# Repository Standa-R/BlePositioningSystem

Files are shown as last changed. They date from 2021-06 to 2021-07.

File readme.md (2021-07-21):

# BLE positioning system

The project includes a short description of source code for Anchors and Tags. PCB design files are also included.

If the use of this source code for Anchors and Tags or PCB design leading to a scientific publication, please, cite our work:

```
@article{Polak_Sensors_2021,
     doi = {10.3390/s21134605},
     url = {https://doi.org/10.3390/s21134605},
     year = {2021},
     month = {July},
     publisher = {MDPI},
     volume = {21},
     number = {13},
     pages = {1--25},
     author = {Ladislav Polak and Stanislav Rozum and Martin Slanina and Tomas Bravenec and Tomas Fryza and Aggelos Pikrakis},
     title = {Received Signal Strength Fingerprinting-Based Indoor Location Estimation Employing Machine Learning},
     journal = {Sensors}
}
```

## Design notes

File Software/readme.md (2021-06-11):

# BleIPS

This folder contains simple application (hastily written) that logs and plots Anchor reports in real time. 

First it subscribes for anchor reports from Raspberry Pi B+ via UDP command. After that it receives anchor reports which are plotted and logged to *csv format.

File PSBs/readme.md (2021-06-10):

# PCB design

This folder contains Anchor's PCB source files from Autodesk Eagle. The mainBoard includes board-to-board connectors for extension boards. There are two extension boards, namely BLEModule and ZigBeeModule. Both are directly put into the schematic of mainBoard.

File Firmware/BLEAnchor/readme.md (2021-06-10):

# BLE anchor firmware

Here you can see the projects for Keil MDK-ARM uVision and STM32CubeMX. 

The MCU runs three cooperative tasks (nonos code):

- BleTask
- ZigBeeTask
- ServiceUartIFTask

## Ble task

Ble task controls four BL652 modules. It starts transmitting/receiving mode deepening on positioning mode (Remote and Self-positioning).

During remote positioning operation it awaits for reports send from BL652 module via uart. Because each advertisementshould be received by all modules we should get four uart messages, each with RSS reading per modules. Due to processing times these messages are not in sync. Therefore the Ble task implements queue. The key for items in queue is address or id of BLE device. On Ble uart report received, the queue is searched and the relevant RSS field in filled. In the device address in not found a new item is created. If all RSS fields are not filled in 4 milliseconds, the report is send regardless of missing readings as they are considered to be not received by the BL652.

## ZigBeeTask

Initializes the communication with ZigBee module ETRX357 and provides interface for control of Anchor.

## ServiceUartIFTask

This task is used as debug service, it saves the messages to buffer and than outputs to uart. It works similarly like prints to standard console output.

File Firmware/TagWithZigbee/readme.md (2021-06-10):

# BLE tag1 firmware (with Zigbee)

Here you can see the projects for Keil MDK-ARM uVision and STM32CubeMX. 

Tag1 uses evaluation board NUCLEO-F429ZI.

The MCU runs three cooperative tasks (nonos code):

- BleTask
- ZigBeeTask
- ServiceUartIFTask

## Ble task

Ble task controls a BL652 modules. It starts transmitting/receiving mode deepening on positioning mode (Remote and Self-positioning).

## ZigBeeTask

Initializes the communication with ZigBee module ETRX357 and provides interface for control of the Tag.

## ServiceUartIFTask

This task is used as debug service, it saves the messages to buffer and than outputs to uart. It works similarly like prints to standard console output.

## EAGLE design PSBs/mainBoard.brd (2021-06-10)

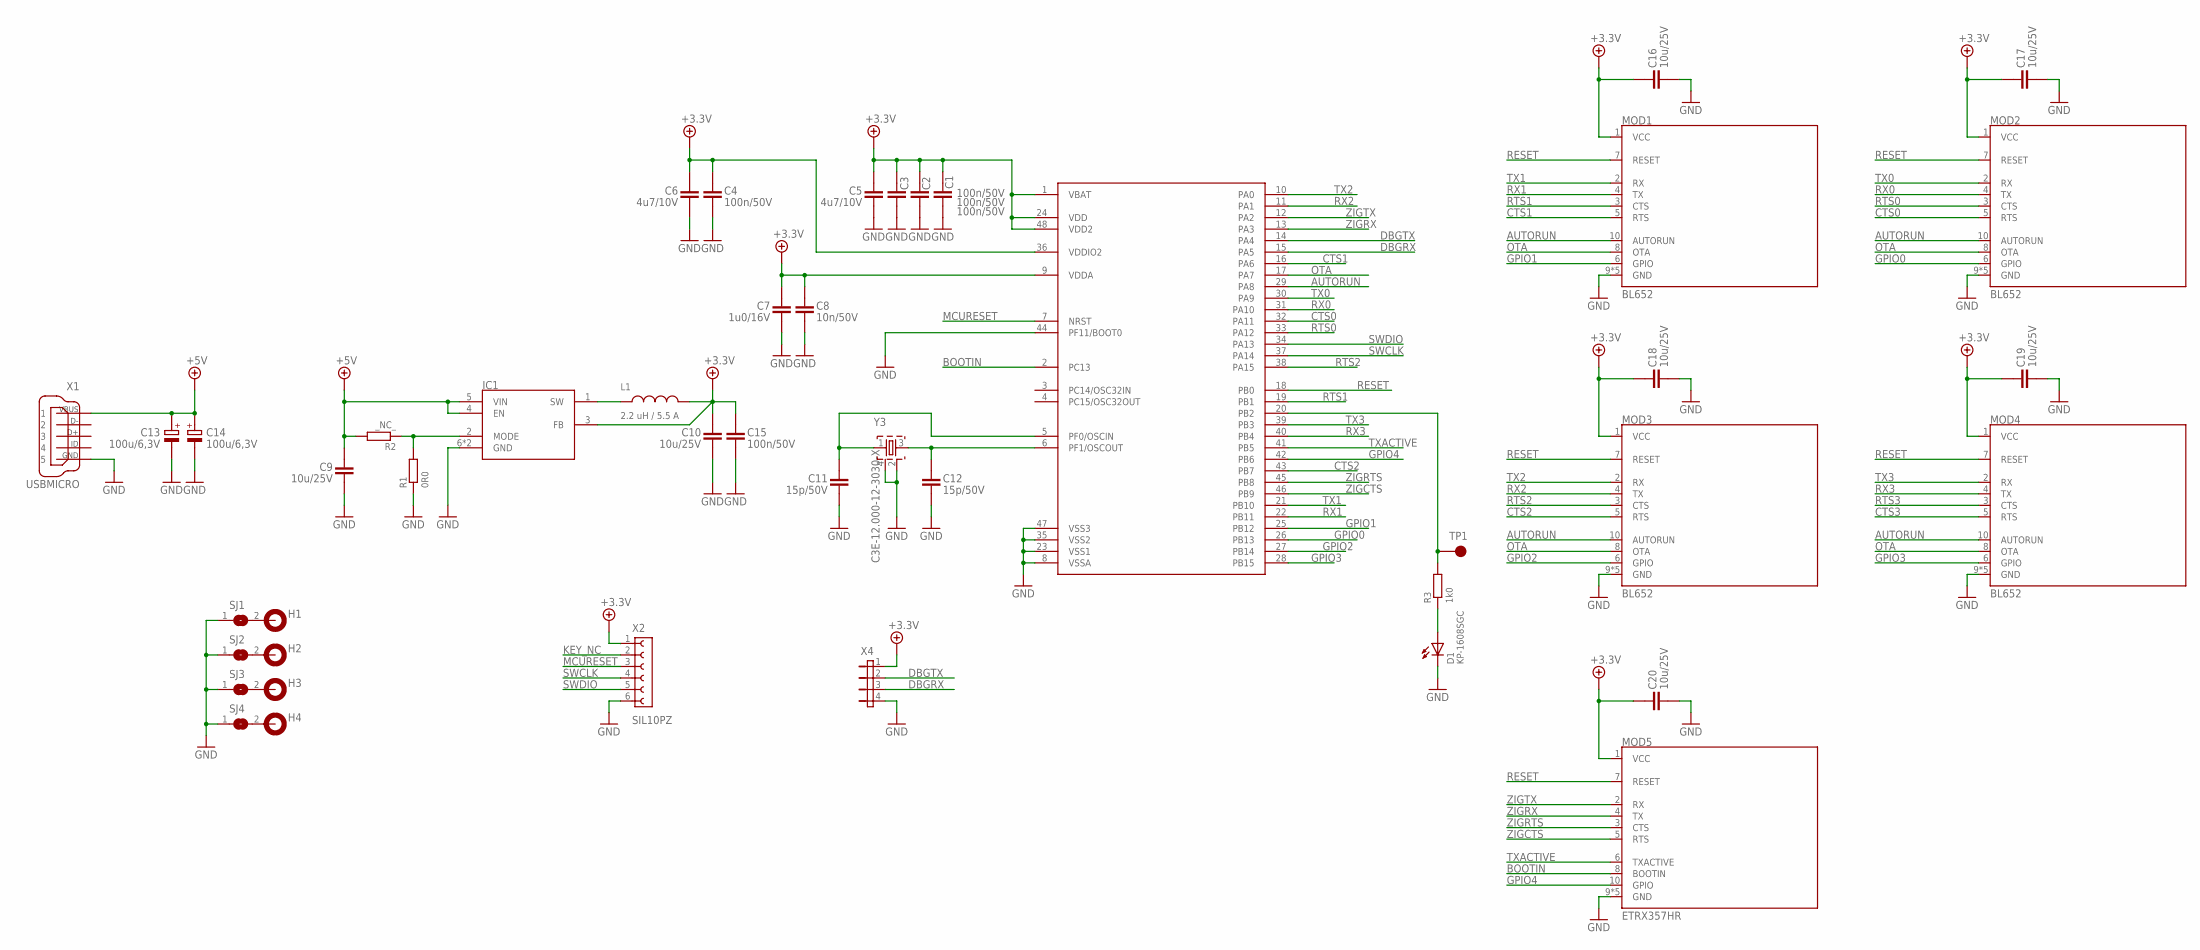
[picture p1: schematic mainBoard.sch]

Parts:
C1, C2, C3, C4, C15: 100N/50V,X7R,+/-10%_0603R; C0603R
C5, C6: 4U7/10V,X5R,+/-10%_0603R; C0603R
C7: 1U0/16V,X5R,+/-10%_0603R; C0603R
C8: 10N/50V,X7R,+/-10%_0603R; C0603R
C9, C10, C16, C17, C18, C19, C20: 10U/25V,X5R,+/-10%_0805R; C0805R
C11, C12: 15P/50V,COG/NPO,+/-5%_0603R; C0603R
C13, C14: 100U; CT6032
D1: KP-1608SGC; 0603
H1, H2, H3, H4: MOUNT-PAD-ROUND4.3; 4.3-PAD
IC0: STM32F091CCT; LQFP48
IC1: TPS62291
L1: 2U2_IHLP2020; 5.49X2X5.18MM
MOD1, MOD2, MOD3, MOD4: BLEMODULE; BLEMOD
MOD5: ZIGBEE; ZIGBEEMOD
R1: 0R0/0.1W,THICK_FILM,1%_0603R; R0603R
R2: _NC_/0.1W,THICK_FILM,1%_0603R; R0603R
R3: 1K0/0.1W,THICK_FILM,1%_0603R; R0603R
SJ1, SJ2, SJ3, SJ4: SJ_1-SMALL; SJ-SMALL
TP1: TEST-PAD_3.5X2-SMD; 3.5X2_SMD
X1: USBMICRO
X2: SOCKET_HADER-1X6; 1X06
X4: PIN_HEADER-1X4; 1X04
Y3: C3E-12.000-12-3030-X; 3.4X2.7X0.75

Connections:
+3.3V: C1.2, C2.2, C3.2, C4.2, C5.2, C6.2, C7.2, C8.2, C10.2, C15.2, C16.2, C17.2, C18.2, C19.2, C20.2, IC0.1 (VBAT), IC0.9 (VDDA), IC0.24 (VDD), IC0.36 (VDDIO2), IC0.48 (VDD2), IC1.3 (FB), L1.P$2 (2), MOD1.1 (VCC), MOD2.1 (VCC), MOD3.1 (VCC), MOD4.1 (VCC), MOD5.1 (VCC), X2.1, X4.1
+5V: C9.2, C13.+, C14.+, IC1.4 (EN), IC1.5 (VIN), R2.2, X1.1
AUTORUN: IC0.29 (PA8), MOD1.10 (AUTORUN), MOD2.10 (AUTORUN), MOD3.10 (AUTORUN), MOD4.10 (AUTORUN)
BOOTIN: IC0.2 (PC13), MOD5.8 (BOOTIN)
CTS0: IC0.32 (PA11), MOD2.5 (RTS)
CTS1: IC0.16 (PA6), MOD1.5 (RTS)
CTS2: IC0.43 (PB7), MOD3.5 (RTS)
CTS3: MOD4.5 (RTS)
DBGRX: IC0.15 (PA5), X4.3
DBGTX: IC0.14 (PA4), X4.2
GND: C1.1, C2.1, C3.1, C4.1, C5.1, C6.1, C7.1, C8.1, C9.1, C10.1, C11.1, C12.1, C13.-, C14.-, C15.1, C16.1, C17.1, C18.1, C19.1, C20.1, D1.2 (C), IC0.8 (VSSA), IC0.23 (VSS1), IC0.35 (VSS2), IC0.44 (PF11/BOOT0), IC0.47 (VSS3), IC1.6 (GND), IC1.EXP (GND), MOD1.9 (GND), MOD1.A1 (GND), MOD1.A2 (GND), MOD1.B1 (GND), MOD1.B2 (GND), MOD2.9 (GND), MOD2.A1 (GND), MOD2.A2 (GND), MOD2.B1 (GND), MOD2.B2 (GND), MOD3.9 (GND), MOD3.A1 (GND), MOD3.A2 (GND), MOD3.B1 (GND), MOD3.B2 (GND), MOD4.9 (GND), MOD4.A1 (GND), MOD4.A2 (GND), MOD4.B1 (GND), MOD4.B2 (GND), MOD5.9 (GND), MOD5.A1 (GND), MOD5.A2 (GND), MOD5.B1 (GND), MOD5.B2 (GND), R1.1, SJ1.1, SJ2.1, SJ3.1, SJ4.1, X1.5, X1.H1 (5), X1.H2 (5), X2.6, X4.4, Y3.2, Y3.4
GPIO0: IC0.26 (PB13), MOD2.6 (GPIO)
GPIO1: IC0.25 (PB12), MOD1.6 (GPIO)
GPIO2: IC0.27 (PB14), MOD3.6 (GPIO)
GPIO3: IC0.28 (PB15), MOD4.6 (GPIO)
GPIO4: IC0.42 (PB6), MOD5.10 (GPIO)
KEY_NC: X2.2
MCURESET: IC0.7 (NRST), X2.3
unnamed: IC1.1 (SW), L1.P$1 (1)
unnamed: D1.1 (A), R3.1
unnamed: IC0.20 (PB2), R3.2, TP1.TP
unnamed: IC1.2 (MODE), R1.2, R2.1
unnamed: H1.1, SJ1.2
unnamed: H2.1, SJ2.2
unnamed: H3.1, SJ3.2
unnamed: H4.1, SJ4.2
unnamed: C11.2, IC0.5 (PF0/OSCIN), Y3.1
unnamed: C12.2, IC0.6 (PF1/OSCOUT), Y3.3
OTA: IC0.17 (PA7), MOD1.8 (OTA), MOD2.8 (OTA), MOD3.8 (OTA), MOD4.8 (OTA)
RESET: IC0.18 (PB0), MOD1.7 (RESET), MOD2.7 (RESET), MOD3.7 (RESET), MOD4.7 (RESET), MOD5.7 (RESET)
RTS0: IC0.33 (PA12), MOD2.3 (CTS)
RTS1: IC0.19 (PB1), MOD1.3 (CTS)
RTS2: IC0.38 (PA15), MOD3.3 (CTS)
RTS3: MOD4.3 (CTS)
RX0: IC0.31 (PA10), MOD2.4 (TX)
RX1: IC0.22 (PB11), MOD1.4 (TX)
RX2: IC0.11 (PA1), MOD3.4 (TX)
RX3: IC0.40 (PB4), MOD4.4 (TX)
SWCLK: IC0.37 (PA14), X2.4
SWDIO: IC0.34 (PA13), X2.5
TX0: IC0.30 (PA9), MOD2.2 (RX)
TX1: IC0.21 (PB10), MOD1.2 (RX)
TX2: IC0.10 (PA0), MOD3.2 (RX)
TX3: IC0.39 (PB3), MOD4.2 (RX)
TXACTIVE: IC0.41 (PB5), MOD5.6 (TXACTIVE)
ZIGCTS: IC0.46 (PB9), MOD5.5 (RTS)
ZIGRTS: IC0.45 (PB8), MOD5.3 (CTS)
ZIGRX: IC0.13 (PA3), MOD5.4 (TX)
ZIGTX: IC0.12 (PA2), MOD5.2 (RX)

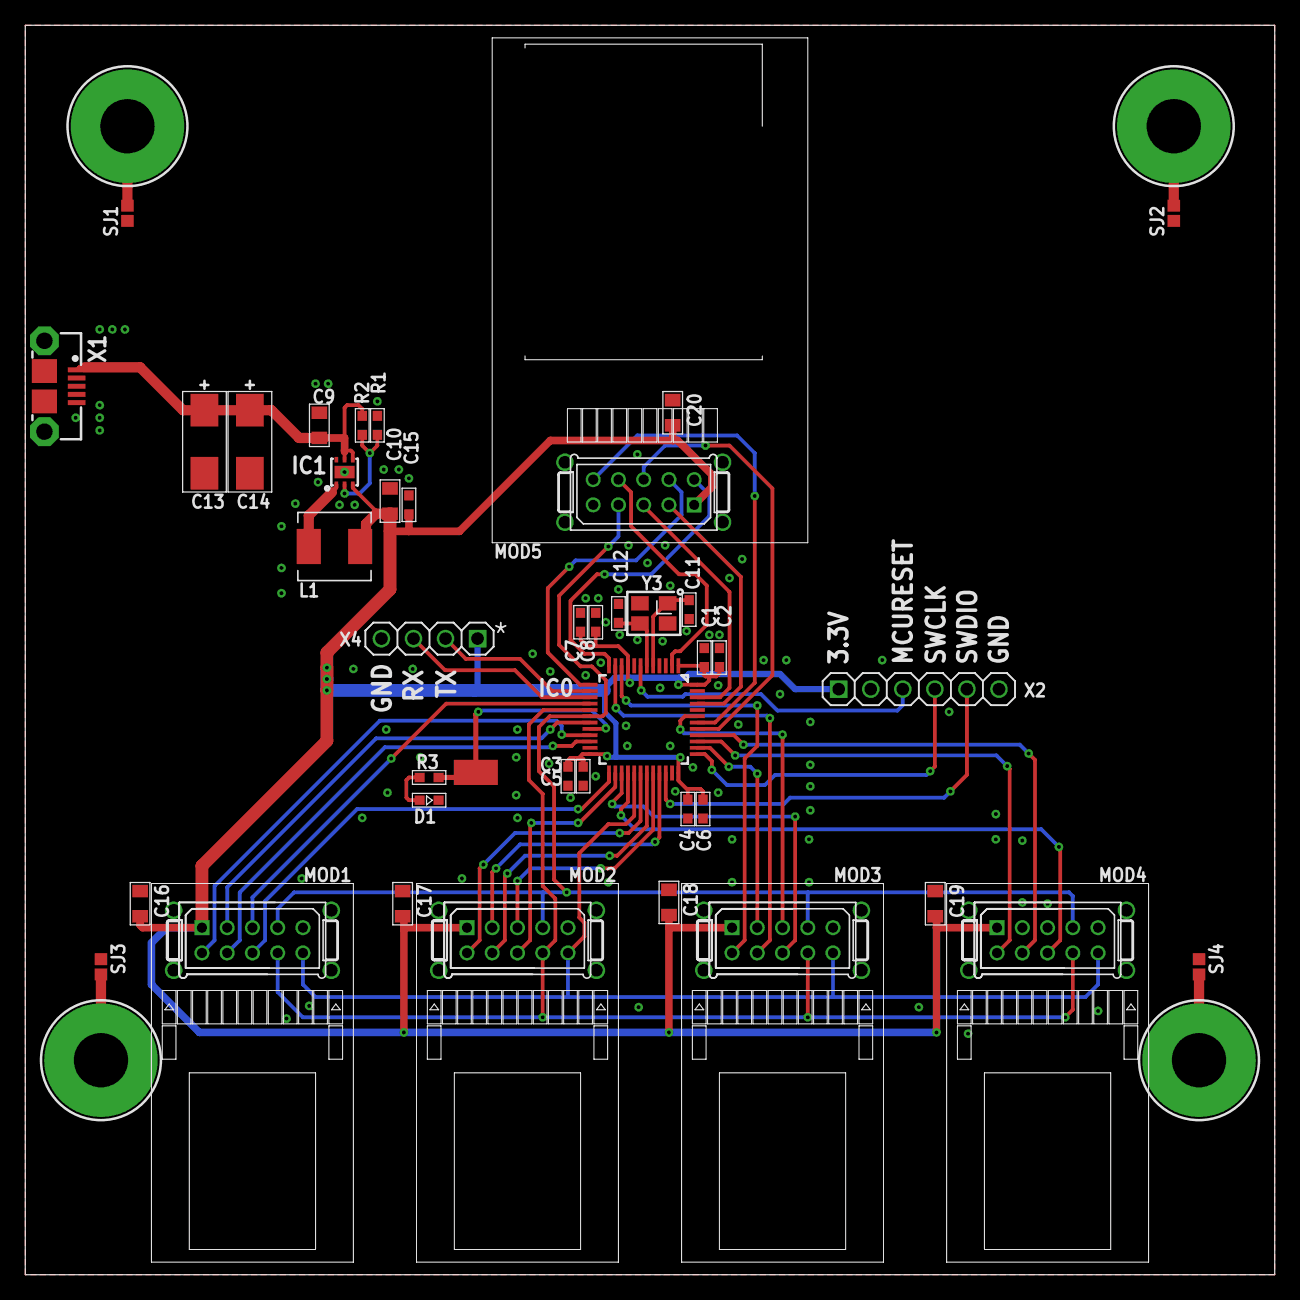
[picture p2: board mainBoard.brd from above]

Board: 4 copper layers, 99.0 x 99.0 mm, 45 parts (0 on the bottom side), 46 nets.

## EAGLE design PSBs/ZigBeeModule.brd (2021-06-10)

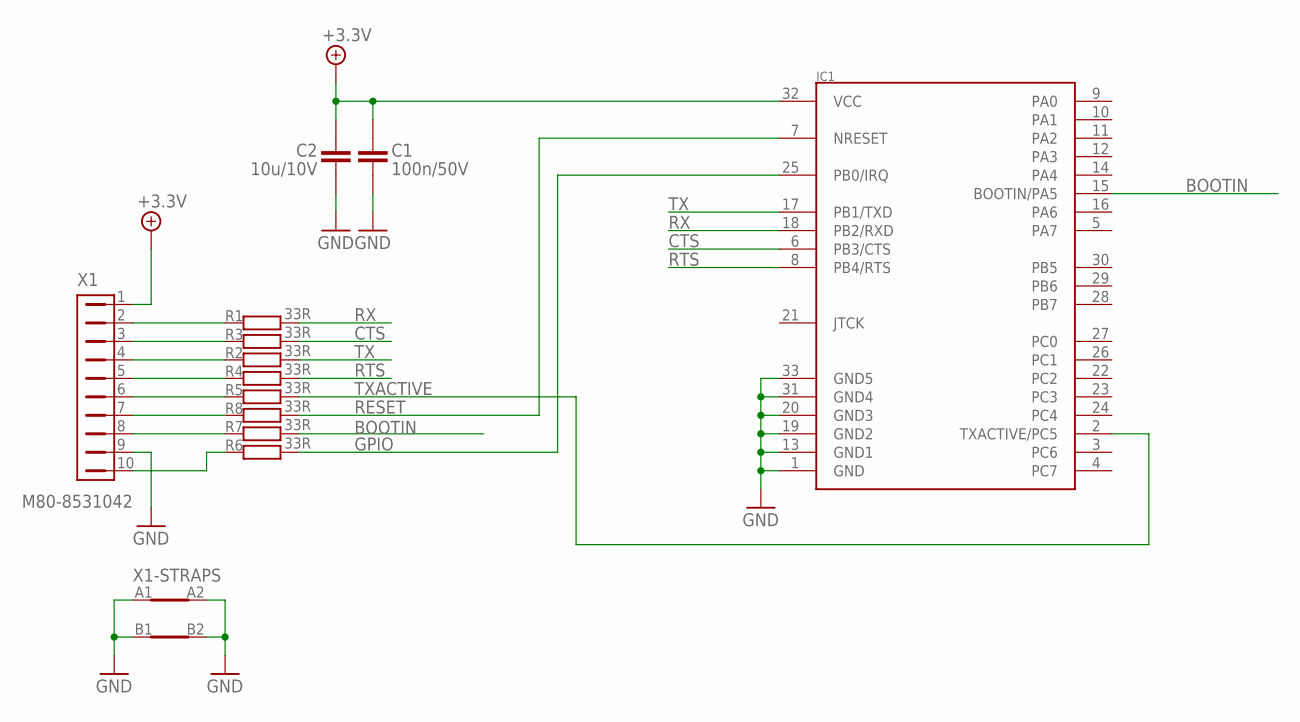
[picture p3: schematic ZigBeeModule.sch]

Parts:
C1: 100N/50V,X7R,+/-10%_0603R; C0603R
C2: 10U/10V,X5R,+/-20%_0603R; C0603R
IC1: ETRX357; ETRX3
R1, R2, R3, R4, R5, R6, R7, R8: 33R/0.1W,THICK_FILM,1%_0603R; R0603R
X1: M80-8531042; M80-85310-W_STRAPS

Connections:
+3.3V: C1.2, C2.2, IC1.32 (VCC), X1.1
BOOTIN: IC1.15 (BOOTIN/PA5), R7.2
CTS: IC1.6 (PB3/CTS), R3.2
GND: C1.1, C2.1, IC1.1 (GND), IC1.13 (GND1), IC1.19 (GND2), IC1.20 (GND3), IC1.31 (GND4), IC1.33 (GND5), X1.9, X1.A1, X1.A2, X1.B1, X1.B2
GPIO: IC1.25 (PB0/IRQ), R6.2
unnamed: R6.1, X1.10
unnamed: R1.1, X1.2
unnamed: R3.1, X1.3
unnamed: R2.1, X1.4
unnamed: R4.1, X1.5
unnamed: R5.1, X1.6
unnamed: R7.1, X1.8
unnamed: R8.1, X1.7
RESET: IC1.7 (NRESET), R8.2
RTS: IC1.8 (PB4/RTS), R4.2
RX: IC1.18 (PB2/RXD), R1.2
TX: IC1.17 (PB1/TXD), R2.2
TXACTIVE: IC1.2 (TXACTIVE/PC5), R5.2

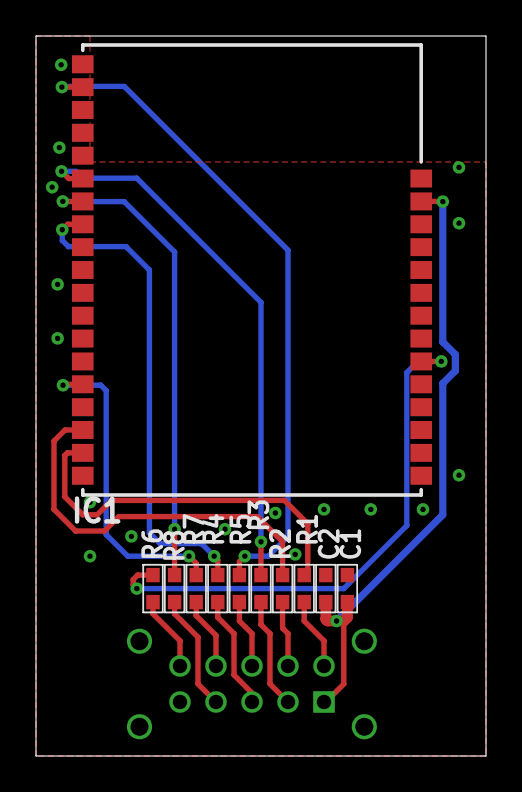
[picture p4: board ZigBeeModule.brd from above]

Board: 4 copper layers, 25.0 x 40.0 mm, 12 parts (1 on the bottom side), 18 nets.

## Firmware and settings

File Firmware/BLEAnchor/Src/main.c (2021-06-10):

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

/* Includes ------------------------------------------------------------------*/
#include "main.h"

/* USER CODE BEGIN Includes */
#include <stdbool.h>
#include <string.h>
#include "BLE.h"
#include "ZigBee.h"
#include "ServiceUartIF.h"

#pragma anon_unions
/* USER CODE END Includes */

RTC_HandleTypeDef hrtc;

UART_HandleTypeDef huart1;
UART_HandleTypeDef huart2;
UART_HandleTypeDef huart3;
UART_HandleTypeDef huart4;
UART_HandleTypeDef huart5;
UART_HandleTypeDef huart6;
DMA_HandleTypeDef hdma_usart1_rx;
DMA_HandleTypeDef hdma_usart1_tx;
DMA_HandleTypeDef hdma_usart2_rx;
DMA_HandleTypeDef hdma_usart2_tx;
DMA_HandleTypeDef hdma_usart3_rx;
DMA_HandleTypeDef hdma_usart3_tx;
DMA_HandleTypeDef hdma_usart4_rx;
DMA_HandleTypeDef hdma_usart4_tx;
DMA_HandleTypeDef hdma_usart5_rx;
DMA_HandleTypeDef hdma_usart5_tx;
DMA_HandleTypeDef hdma_usart6_rx;
DMA_HandleTypeDef hdma_usart6_tx;

void SystemClock_Config(void);
static void MX_GPIO_Init(void);
static void MX_DMA_Init(void);
static void MX_RTC_Init(void);
static void MX_USART1_UART_Init(void);
static void MX_USART2_UART_Init(void);
static void MX_USART3_UART_Init(void);
static void MX_USART4_UART_Init(void);
static void MX_USART5_UART_Init(void);
static void MX_USART6_UART_Init(void);
/* USER CODE BEGIN 0 */


//#define BUFFER_SIZE 256  /* must be power of two */
#define TX_BUFFER_SIZE 1024
//#define COMMAND_BUFFER_SIZE 128

void HAL_UART_ErrorCallback(UART_HandleTypeDef *huart)
{
    if(huart == &huart3)
    {
        if(huart->ErrorCode == HAL_UART_ERROR_FE)
        {
            __HAL_UART_CLEAR_FEFLAG(huart);
        }
    }
    
    if(huart == &huart2)
    {
        if(huart->ErrorCode == HAL_UART_ERROR_FE)
        {
            __HAL_UART_CLEAR_FEFLAG(huart);
        }
        ZigBeeReinitializeDMA();
    }
}



/* USER CODE END 0 */

/**
  * @brief  The application entry point.
  * @retval int
  */
int main(void)
{
  /* MCU Configuration--------------------------------------------------------*/

  /* Reset of all peripherals, Initializes the Flash interface and the Systick. */
  HAL_Init();

  /* Configure the system clock */
  SystemClock_Config();

  /* Initialize all configured peripherals */
  MX_GPIO_Init();
  MX_DMA_Init();
  MX_RTC_Init();
  MX_USART1_UART_Init();
  MX_USART2_UART_Init();
  MX_USART3_UART_Init();
  MX_USART4_UART_Init();
  MX_USART5_UART_Init();
  MX_USART6_UART_Init();
  /* USER CODE BEGIN 2 */
  
  


  HAL_GPIO_WritePin(BOOTIN_GPIO_Port, BOOTIN_Pin, GPIO_PIN_SET);    //do not boot in bootloader mode (RTX357)

  HAL_Delay(200);

  HAL_GPIO_WritePin(LED_GPIO_Port, LED_Pin, GPIO_PIN_SET);
  HAL_GPIO_WritePin(Reset_GPIO_Port, Reset_Pin, GPIO_PIN_SET);
  
  HAL_Delay(200);

  
  

  ServiceUartIFInit(&huart6);
  ZigBeeInit(&huart2);
  BleInit(&huart3, &huart1, &huart4, &huart5);
  

  
  /* USER CODE END 2 */

  /* Infinite loop */
  /* USER CODE BEGIN WHILE */
  //QueueItem *qi;
  
  while (1)
  {
    /* USER CODE END WHILE */

    /* USER CODE BEGIN 3 */
      BleTask();
      ZigBeeTask();
      ServiceUartIFTask();
      
  }
  /* USER CODE END 3 */
}

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


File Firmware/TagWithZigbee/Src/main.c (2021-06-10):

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

/* Includes ------------------------------------------------------------------*/
#include "main.h"

/* USER CODE BEGIN Includes */
#include "ServiceUartIF.h"
#include "ZigBee.h"
#include "BLE.h"

/* USER CODE END Includes */

UART_HandleTypeDef huart2;
UART_HandleTypeDef huart3;
UART_HandleTypeDef huart6;
DMA_HandleTypeDef hdma_usart2_rx;
DMA_HandleTypeDef hdma_usart2_tx;
DMA_HandleTypeDef hdma_usart3_rx;
DMA_HandleTypeDef hdma_usart3_tx;
DMA_HandleTypeDef hdma_usart6_rx;
DMA_HandleTypeDef hdma_usart6_tx;

void SystemClock_Config(void);
static void MX_GPIO_Init(void);
static void MX_DMA_Init(void);
static void MX_USART3_UART_Init(void);
static void MX_USART6_UART_Init(void);
static void MX_USART2_UART_Init(void);
/* USER CODE BEGIN 0 */
static uint32_t delay;


void HAL_UART_ErrorCallback(UART_HandleTypeDef *huart)
{
    if(huart == &huart2)
    {
        if(huart->ErrorCode == HAL_UART_ERROR_FE)
        {
            __HAL_UART_CLEAR_FEFLAG(huart);
        }
    }
    
    if(huart == &huart2)
    {
        if(huart->ErrorCode == HAL_UART_ERROR_FE)
        {
            __HAL_UART_CLEAR_FEFLAG(huart);
        }
    }
}

/* USER CODE END 0 */

/**
  * @brief  The application entry point.
  * @retval int
  */
int main(void)
{
  

  /* MCU Configuration--------------------------------------------------------*/

  /* Reset of all peripherals, Initializes the Flash interface and the Systick. */
  HAL_Init();

  /* Configure the system clock */
  SystemClock_Config();

  /* Initialize all configured peripherals */
  MX_GPIO_Init();
  MX_DMA_Init();
  MX_USART3_UART_Init();
  MX_USART6_UART_Init();
  MX_USART2_UART_Init();
  /* USER CODE BEGIN 2 */
  ServiceUartIFInit(&huart3);
  BleInit(&huart2);
  ZigBeeInit(&huart6);

  /* USER CODE END 2 */

  /* Infinite loop */
  /* USER CODE BEGIN WHILE */
  while (1)
  {
      if(HAL_GetTick() >= delay + 1000)
      {
          delay = HAL_GetTick();
          HAL_GPIO_TogglePin(LD2_GPIO_Port, LD1_Pin);
          
          //ServiceUartIFPrint("MainThread tick: %u\n", delay);
          
          uint8_t tmpData[20];
          
          //ZigBeeQueueNewReport(tmpData);
          //hdma_usart3_rx.Instance->
      }
      
    /* USER CODE END WHILE */

    /* USER CODE BEGIN 3 */
    ServiceUartIFTask();
    ZigBeeTask();
    BleTask();
  }
  /* USER CODE END 3 */
}

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


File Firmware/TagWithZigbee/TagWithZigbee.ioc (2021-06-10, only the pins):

Mcu.UserName=STM32F429ZITx
PA1.GPIO_Label=RMII_REF_CLK [LAN8742A-CZ-TR_REFCLK0]
PA1.Signal=ETH_REF_CLK
PA10.GPIO_Label=USB_ID
PA10.Signal=USB_OTG_FS_ID
PA11.GPIO_Label=USB_DM
PA11.Signal=USB_OTG_FS_DM
PA12.GPIO_Label=USB_DP
PA12.Signal=USB_OTG_FS_DP
PA13.GPIO_Label=TMS
PA13.Signal=SYS_JTMS-SWDIO
PA14.GPIO_Label=TCK
PA14.Signal=SYS_JTCK-SWCLK
PA2.GPIO_Label=RMII_MDIO [LAN8742A-CZ-TR_MDIO]
PA2.Signal=ETH_MDIO
PA7.GPIO_Label=RMII_CRS_DV [LAN8742A-CZ-TR_CRS_DV]
PA7.Signal=ETH_CRS_DV
PA8.GPIO_Label=USB_SOF [TP1]
PA8.Signal=USB_OTG_FS_SOF
PA9.GPIO_Label=USB_VBUS
PA9.Signal=USB_OTG_FS_VBUS
PB0.GPIO_Label=LD1
PB0.Signal=GPIO_Output
PB13.GPIO_Label=RMII_TXD1 [LAN8742A-CZ-TR_TXD1]
PB13.Signal=ETH_TXD1
PB14.GPIO_Label=LD3 [Red]
PB14.Signal=GPIO_Output
PB7.GPIO_Label=LD2 [Blue]
PB7.Signal=GPIO_Output
PC1.GPIO_Label=RMII_MDC [LAN8742A-CZ-TR_MDC]
PC1.Signal=ETH_MDC
PC13.GPIO_Label=USER_Btn [B1]
PC13.Signal=GPXTI13
PC14/OSC32_IN.Signal=RCC_OSC32_IN
PC15/OSC32_OUT.Signal=RCC_OSC32_OUT
PC4.GPIO_Label=RMII_RXD0 [LAN8742A-CZ-TR_RXD0]
PC4.Signal=ETH_RXD0
PC5.GPIO_Label=RMII_RXD1 [LAN8742A-CZ-TR_RXD1]
PC5.Signal=ETH_RXD1
PD5.Signal=USART2_TX
PD6.Signal=USART2_RX
PD8.GPIO_Label=STLK_RX [STM32F103CBT6_PA3]
PD8.Signal=USART3_TX
PD9.GPIO_Label=STLK_TX [STM32F103CBT6_PA2]
PD9.Signal=USART3_RX
PG11.GPIO_Label=RMII_TX_EN [LAN8742A-CZ-TR_TXEN]
PG11.Signal=ETH_TX_EN
PG13.GPIO_Label=RMII_TXD0 [LAN8742A-CZ-TR_TXD0]
PG13.Signal=ETH_TXD0
PG14.Signal=USART6_TX
PG6.GPIO_Label=USB_PowerSwitchOn [STMPS2151STR_EN]
PG6.Signal=GPIO_Output
PG7.GPIO_Label=USB_OverCurrent [STMPS2151STR_FAULT]
PG7.Signal=GPIO_Input
PG9.Signal=USART6_RX
PH0/OSC_IN.GPIO_Label=MCO [STM32F103CBT6_PA8]
PH0/OSC_IN.Signal=RCC_OSC_IN
PH1/OSC_OUT.Signal=RCC_OSC_OUT

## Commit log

2021-06-11 added software folder, the software runs on PC and logs messages from Raspberry Pi B+
2021-07-21 Update readme.md
    added curly brackets around year value

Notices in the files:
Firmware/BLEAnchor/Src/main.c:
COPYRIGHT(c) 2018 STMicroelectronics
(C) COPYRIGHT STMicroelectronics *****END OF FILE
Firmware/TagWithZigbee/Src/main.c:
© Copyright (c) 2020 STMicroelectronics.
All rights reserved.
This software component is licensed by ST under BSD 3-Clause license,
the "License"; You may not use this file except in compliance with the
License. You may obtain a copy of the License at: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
